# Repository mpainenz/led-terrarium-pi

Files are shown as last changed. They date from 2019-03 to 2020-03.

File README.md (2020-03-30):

<div class="main-content">
  <h2 id="how-to-build-your-own-raspberry-pi-powered-terrarium">Build your own Raspberry Pi powered Terrarium</h2>
  <p>Use a Raspberry Pi to control LED lighting for a terrarium. 
    Download the code I've shared on <a href="https://github.com/mpainenz/led-terrarium-pi">my Github page</a>, and build your own!
  </p>
  <ul>  
    <li>Changes colour throughout the sunrise, day, sunset, and night</li>  
    <li>Uses your geographical location to calculate the actual sunrise and sunset times to use</li>
  </ul>

  <h2 id="you-will-need">You will need...</h2>
  <ul>
    <li>A Raspberry Pi (any version will do)</li>
    <li>A Terrarium</li>
    <li>A White LED Light strip (to provide light to the plants)</li>
    <li>An RGB LED Light strip (to provide color effects)</li>
    <li>A 12v DC Power Supply</li>   
    <li>A 12v to 5v UBEC (Powers your Pi from the same 12v supply as the LED strips)</li>
    <li>A soldering iron and solder</li>
    <li>4 x MOSFET Transistors (Used in the lighting circuits)</li>
    <li>4 x Resistors (Also used in the lighting circuits)</li>
    <li>Various lengths of electrical wire</li>
  </ul>

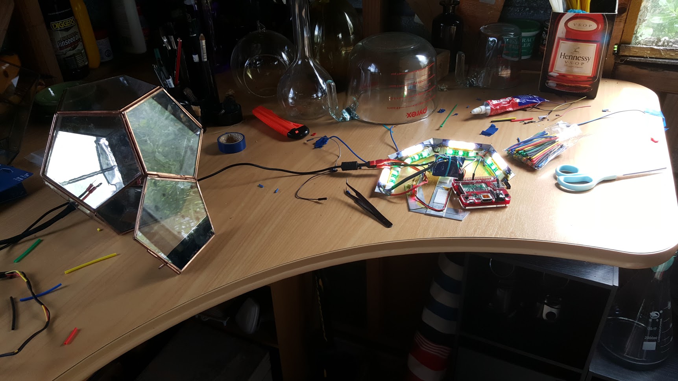
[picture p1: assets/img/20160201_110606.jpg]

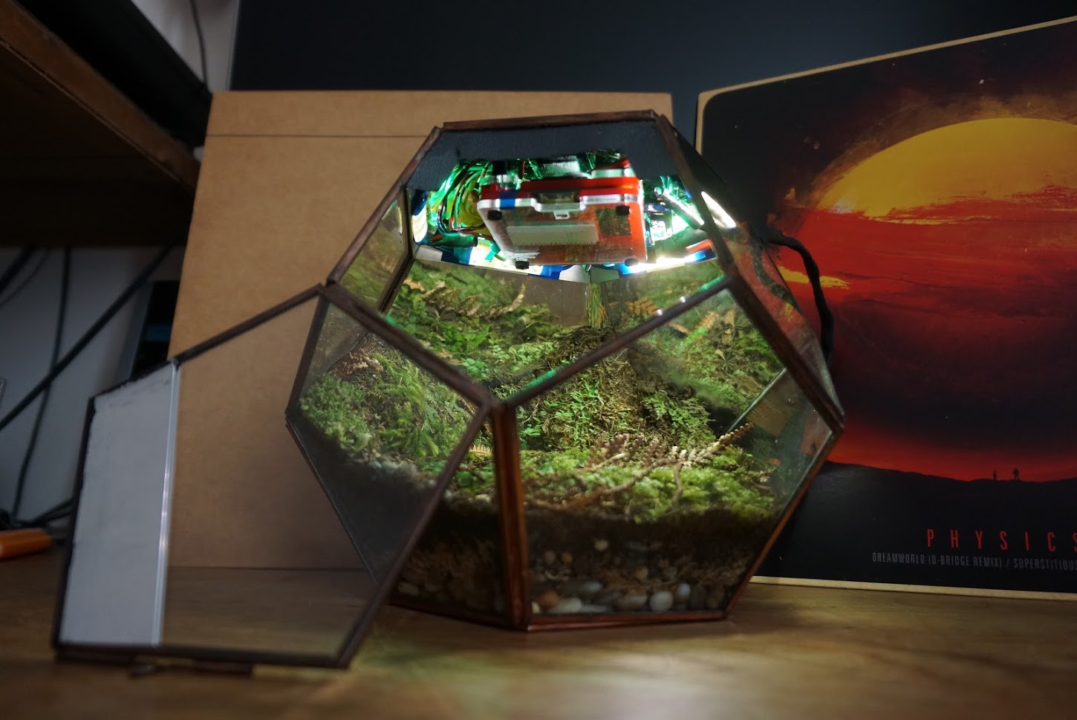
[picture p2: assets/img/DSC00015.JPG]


<h2 id="lets-get-started">Lets get started</h2>

<p>It might seem complicated, but it's pretty straight forward once we break it down into parts. Keep scrolling and we can go through each step. If you get stuck, feel free to send me an email. Perhaps I could make one for you?</p>
  
<p>Keep scrolling for more...</p>

</div>

<div class="main-content">

<h2 id="led-terrarium-pi">Powering the lights</h2>
<p>How can a Raspberry Pi control LED lighting?</p>

<p>All Raspberry Pi's come with a series of GPIO pins which you can control.</p>



<p>GPIO pins either accept an input voltage which can be read, or can be setup to output a voltage signal. In this case, we want to power our LED lights, so we want to output a signal. In our software, we tell the Raspberry Pi that we want to use three pins to control the RGB light strip (one for each colour), and one pin to control the White LED strip.</p>

<p>Sounds simple right? Unfortunately there are two problems...</p>

<ul>
  <li>The LED strips require 12 volts, but the GPIO pins only output 3.3 volts. </li>
  <li>The output voltage on the GPIO pins can either be 3.3v or 0v. There's no in-between. For an RGB light strip to show a full range of colours, or a white strip to be at varying brightnesses, we need the values in between the min and max voltage</li>
</ul>

<p>Fortunately, we have solutions to both of these issues. </p>

<h2 id="led-terrarium-pi">MOSFET</h2>

<p>Instead of using the Raspberry Pi GPIO pins to power the LED strips (which wouldn't work because the output voltage is too low at 3.3v when we need 12v), we will instead power the LED strips off a 12v power supply, and introduce a MOSFET into that circuit.</p>
  
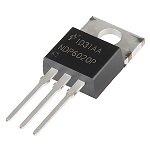
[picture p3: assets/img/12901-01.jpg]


<p>Think of the MOSFET here as a type of switch. The MOSFET has two circuits running through it. When current passes through one of those circuits, it opens the other circuit. </p>

<p align="center">
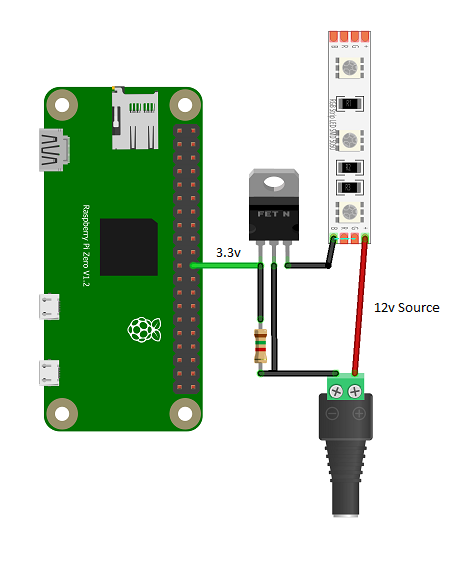
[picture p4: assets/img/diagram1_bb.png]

</p>

<p>We connect our Raspberry Pi and our LED light strip to our MOSFET. I've shown one MOSFET here, but we would need to add one per colour on the RGB strip, and another one for our White LED strip. Each of these are controlled separately to achieve a full colour spectrum.</p>

<p align="center">
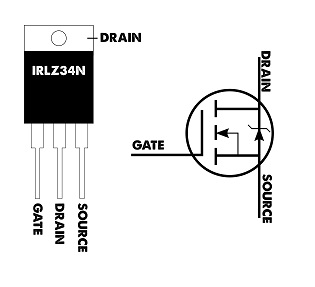
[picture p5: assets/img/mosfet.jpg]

</p>
  
<p>A MOSFET has three pins. From left to right, Gate, Drain, Source.</p>
<ul>
  <li>The Gate pin is what is connected to the Raspberry Pi, and is used to open the Source/Drain circuit. You might notice that we need to also connect the Gate pin to negative with a resistor. When voltage is applied to the Gate pin, it charges up like a capacitor, so it must also be attached to negative with a resistor. If you skip that step, the gate will remain open when voltage is not being applied. The resistor allows the Gate to discharge.</li>
  
  <li>The Source and Drain pins are attached to the LED circuit. Unless voltage is being applied to the Gate, this circuit remains closed.</li>
</ul>

<p>The part I have used here (Part Number IRLZ34N) is a perfect fit for a 12v LED light circuit. It is rated to work with the Raspberry Pi's 3.3v output and the 12v light circuit. There are two types of MOSFETS, and they are wired differently. This is an N-type MOSFET.</p>

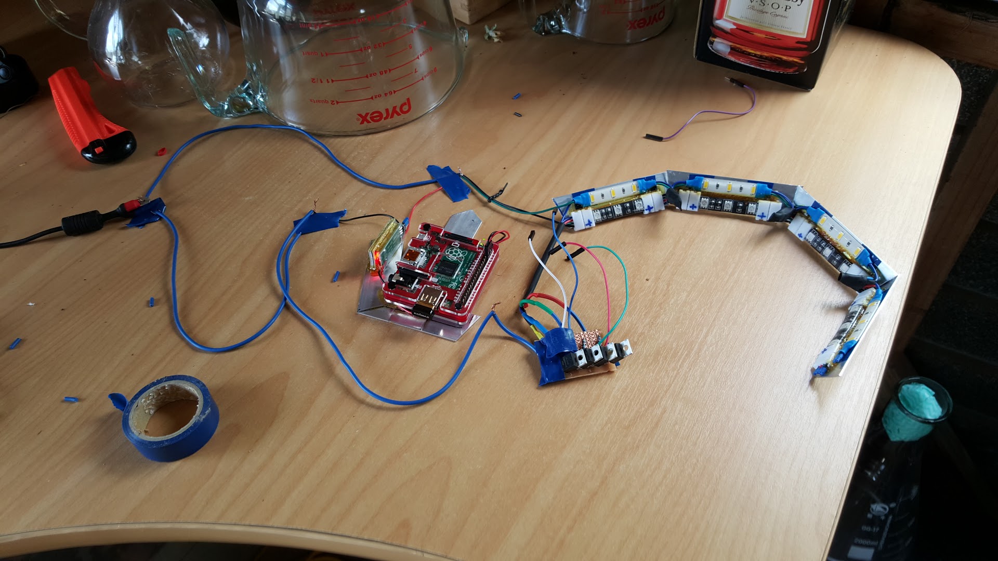
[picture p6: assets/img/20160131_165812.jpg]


<p>It can be helpful to use a little PCB board to attach the MOSFETs to. The image above was my first attempt. I ended up redoing this part, and not using a PCB. Instead I just used solder, wire, and heat shrink to save a little space.</p>

<p>You might notice that in the picture above, I'm also using the 12v power source to power the Raspberry Pi. The Raspberry Pi can accept 5v power into the GPIO interface. How do we step down from 12v to 5v? We can use a 12v to 5v UBEC. This accepts a 12v source, and outputs a 5v current. This step is optional, you could just use a normal 5v power supply, but I wanted to only have one cable going into the terrarium</p>

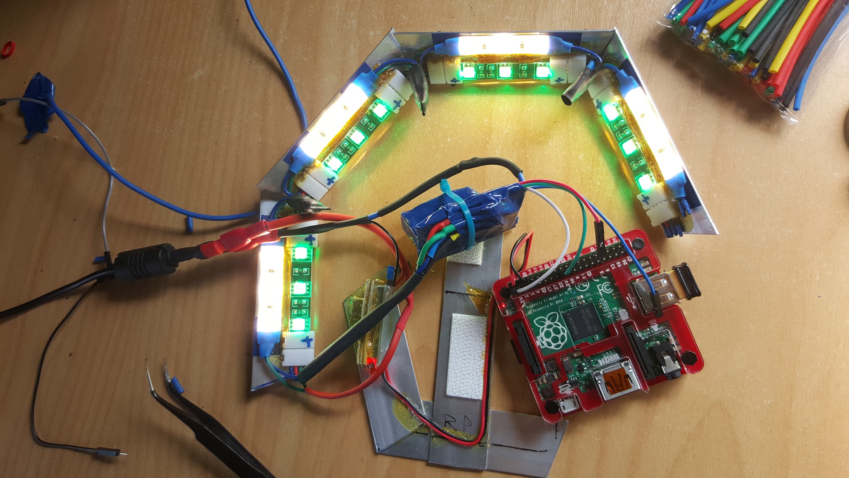
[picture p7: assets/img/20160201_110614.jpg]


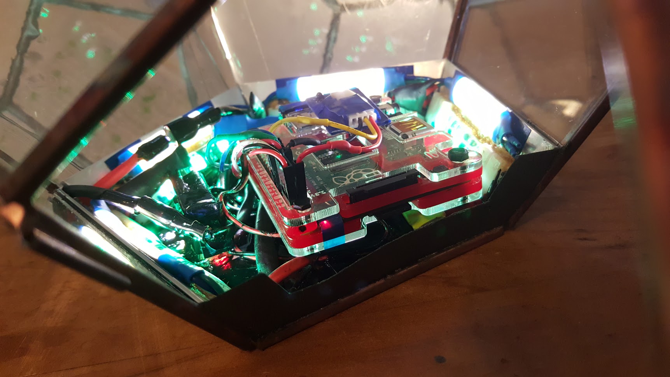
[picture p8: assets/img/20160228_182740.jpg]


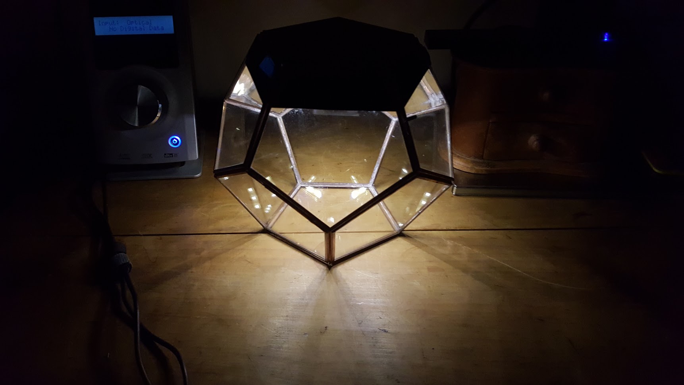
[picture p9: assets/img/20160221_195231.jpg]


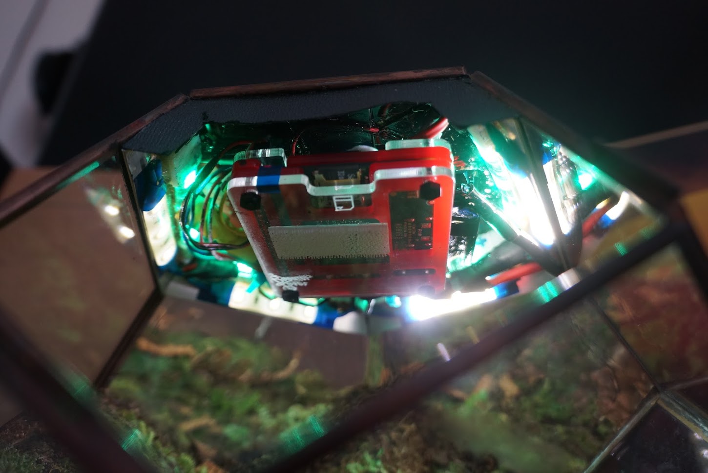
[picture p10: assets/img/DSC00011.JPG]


</div>

<div class="main-content">

<h2 id="led-terrarium-pi">Controlling the lights</h2>

<p>I mentioned earlier that there is another issue here. Our LED strips are analogue. They accept any current between 0v and 12v. For the RGB light strip, to generate a wide selection of colours, that means we want to use all sorts of voltages.</p>

<p>When the Raspberry Pi is instructed to send an output voltage to our MOSFET, it can only send either 0v or 3.3v. There is no in-between. If we could half the voltage and send 1.65v to the gate of the mosfet, we would expect around 6v of current on the light circuit.</p>

<p>So what can we do?</p>

<h2 id="led-terrarium-pi">Pulse Width Modulation</h2>

<p>Feel free to skip this section if you want, I've handled this in the code so you don't really need to understand this part. But if you are interested, what we can do is quickly alternate the output 3.3v signal on and off many times a second. We can then have the software turn that signal on for longer, or off for longer, depending on what voltage we want to try and emulate.</p>

<p align="center">
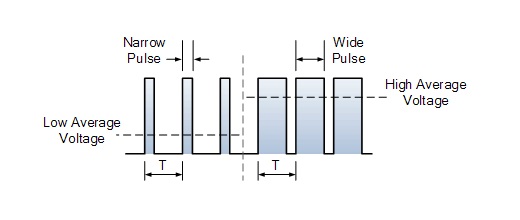
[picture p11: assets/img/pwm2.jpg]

</p>
  
</div>

<div class="main-content">

<h2 id="led-terrarium-pi">The fun part</h2>

<p>Now that the hard part is done, putting the terrarium together can start. For mine, I chose to try and build a closed terrarium and grow mosses, lichens, and other moisture loving plants.</p>

<p>To create a healthy enviroment for the plants, it's useful to create an area in the bottom of the container which contains either spagnum moss, or charcoal. My understanding is that this can help to prevent toxic compounds from lingering in the bottom where the water drains. It will help to prevent the envirment in the soil turning anaerobic, and will be more beneficial to the health of the overall system</p>

<p>For my terrarium, I used...</p>
  
  <ul>
    <li>Wild plants and mosses collected from nature</li>
    <li>Small rocks</li>
    <li>Medium sized rocks</li>
    <li>Cacti and Succulent Potting Mix (Formulated to drain very well)</li>
    <li>Spagnum Moss</li>
    <li>Charcoal</li>
    <li>A Coffee Filter</li>
  </ul>
  
<p align="center">
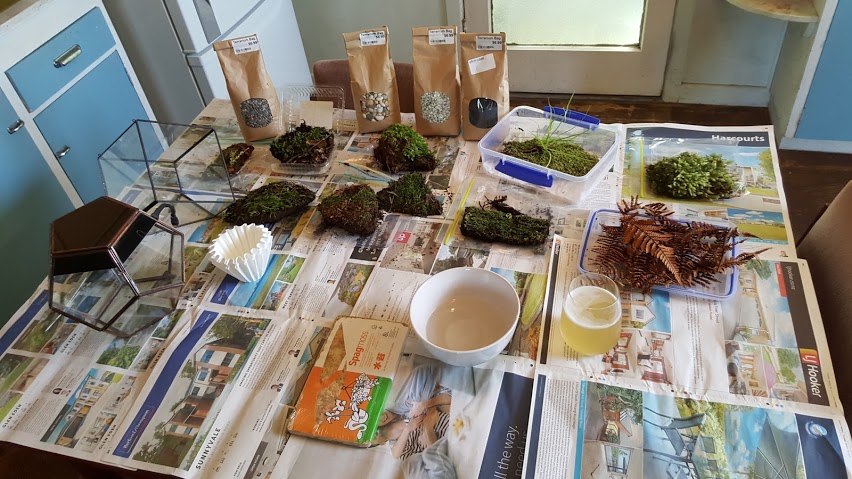
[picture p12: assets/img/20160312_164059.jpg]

</p>

<p>First I started with large rocks at the bottom</p>

<p align="center">
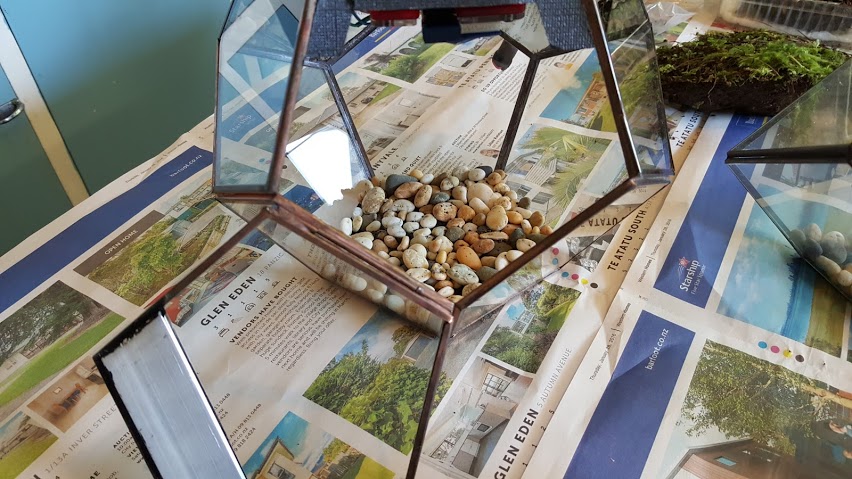
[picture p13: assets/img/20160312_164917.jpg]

</p>

<p>Next I placed a piece of Coffee filter paper on top </p>

<p align="center">
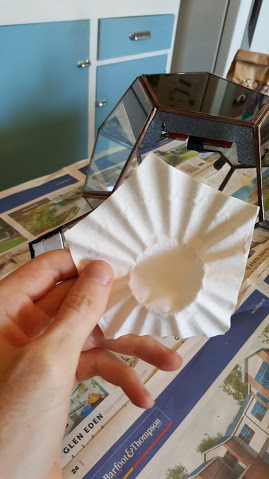
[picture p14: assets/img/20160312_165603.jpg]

</p>

<p>And on top of that, a combination of Spagnum Moss and crushed Charcoal (be sure not to use any charcoal that might have a chemical accelerant added to it to help it burn faster)</p>

<p align="center">
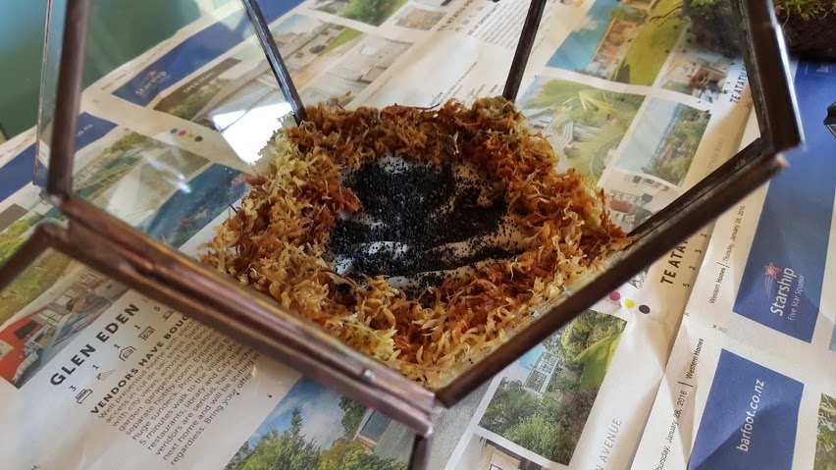
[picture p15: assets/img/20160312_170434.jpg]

</p>

<p>On top of that some small rocks</p>

<p align="center">
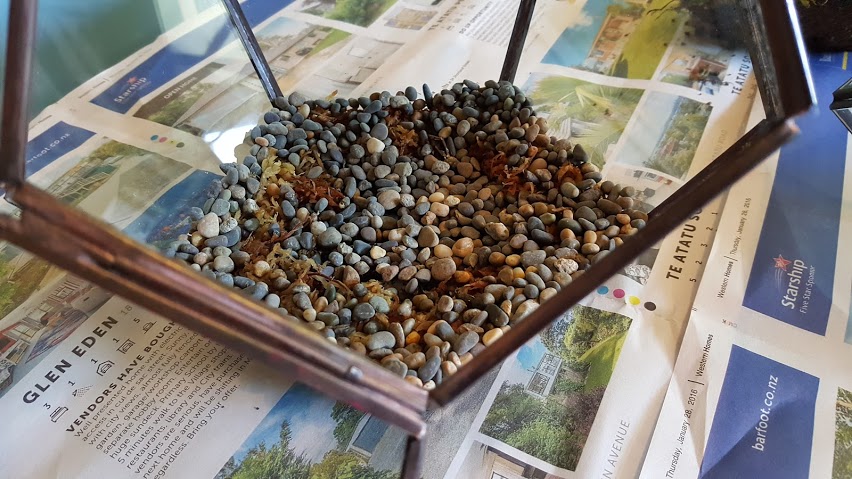
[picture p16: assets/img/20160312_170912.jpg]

</p>

<p>And on top of that some potting mix</p>

<p align="center">
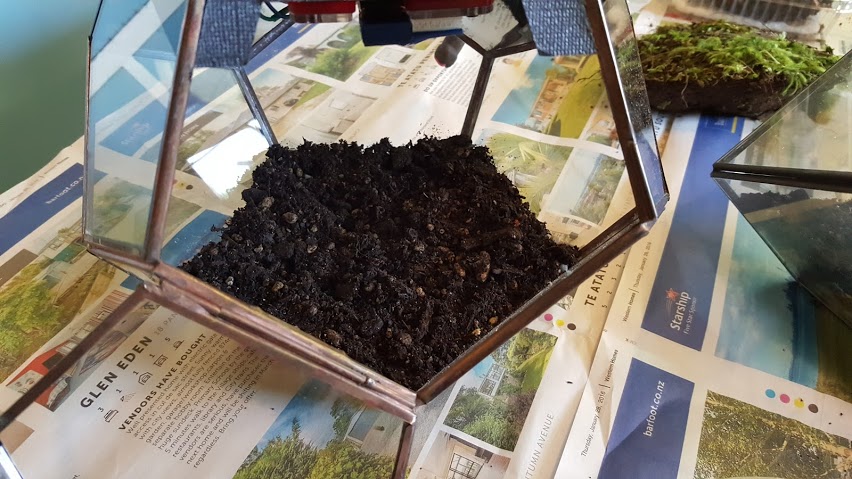
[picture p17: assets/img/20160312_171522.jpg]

</p>

<p>Now that we have a functional drainage and bedding layer, the plants can be added. This part was difficult to photograph, but essentially it's a bit of a jigsaw puzzle, and is really an art form in itself. </p>

<p align="center">
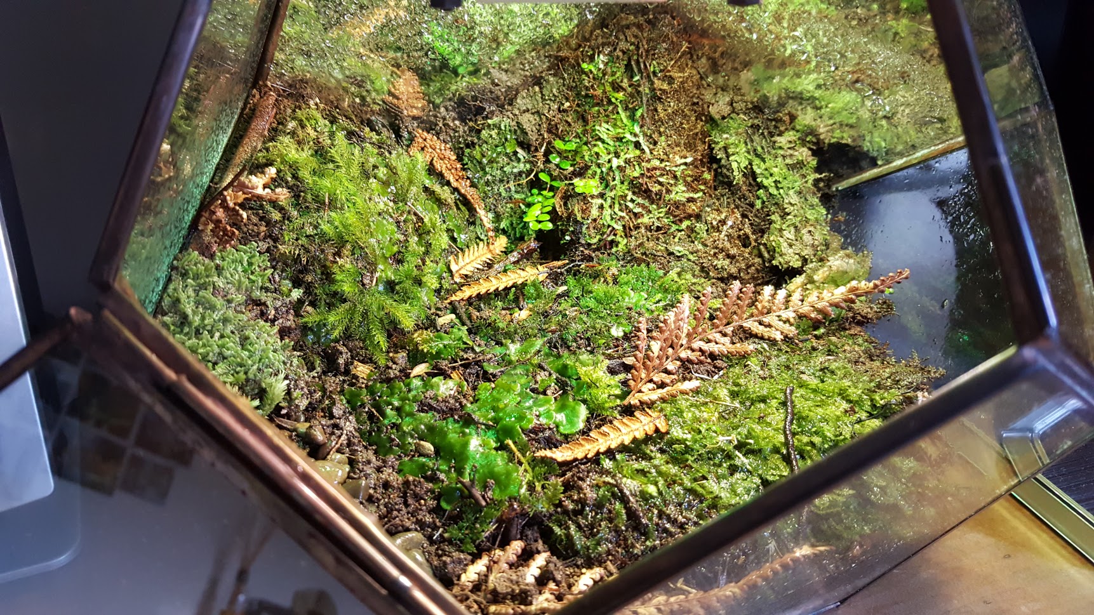
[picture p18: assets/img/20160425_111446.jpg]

</p>

</div>

<div class="main-content">

<h2 id="led-terrarium-pi">Installing the software</h2>

<p>Firstly prepare a Rasperry Pi by installing Raspian OS, and set the Timezone on your Raspberry Pi with ‘sudo raspi-config’ command. (Defaults to UTC)</p>

<p>Requirements:</p>
<ul>
  <li>Python 2.7 (comes by default)</li>
  <li>pigpio (comes by default)</li>
</ul>

<p>Python Libraries</p>
<ul>
  <li>ephem (Astronomical library to work out Sunrise/Sunset) - <code class="highlighter-rouge">sudo pip install ephem</code></li>
</ul>

<p>To install my light controller script, simply copy the main.py, terrarium_lights.py, and config.py files to a directory of the Raspberry Pi, and type the following commands</p>

<code class="highlighter-rouge">pigpiod</code>

<code class="highlighter-rouge">sudo python main.py</code>

<p>The first command starts the GPIO daemon, and the second command runs my script. The GPIO daemon is the software the Raspberry Pi uses to send and receieve signals over the GPIO interface</p>

<h2 id="led-terrarium-pi">Changing your settings</h2>

<p>Modify the config.py file and provide your latitude & longitude to allow the script to give you the correct day/night cycle for your location.</p>

<p>Optionally you can also specify which GPIO pins to use. The default is as follows:</p>
<ul>
  <li>Red: 25</li>
  <li>Green: 27</li>
  <li>Blue: 22</li>
  <li>White: 18</li>  
</ul>

<h2 id="about-me">About me</h2>
<p>Hi, My name is Mark Paine, I'm a software developer based in New Zealand. I love nature, electronics, and programming. It was great to combine it all together and produce this guide. I hope you enjoyed reading it.</p>

<p>If you have any questions or comments, feel free to get in touch either here in the 'issues' section of the GitHub page, or via email on <a href = "mailto: mpainenz@gmail.com">mpainenz@gmail.com</a></p>

<p>If you create your own terrarium using this guide, send me a photo.</p>

<p>Do you love this Terrarium, but can't build your own? Perhaps I can build you one? Get in touch. :)</p>

</div>

<div class="main-content">

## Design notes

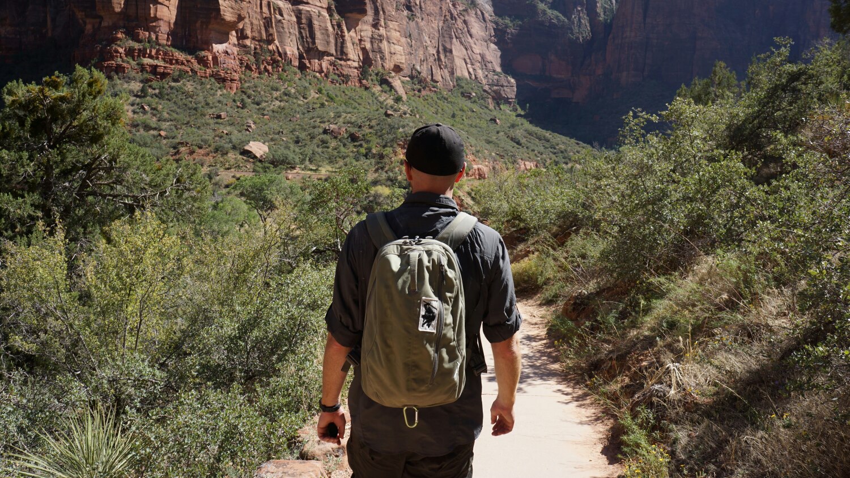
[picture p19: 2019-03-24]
assets/img/51833_10151268154790850_972230833_o.jpg

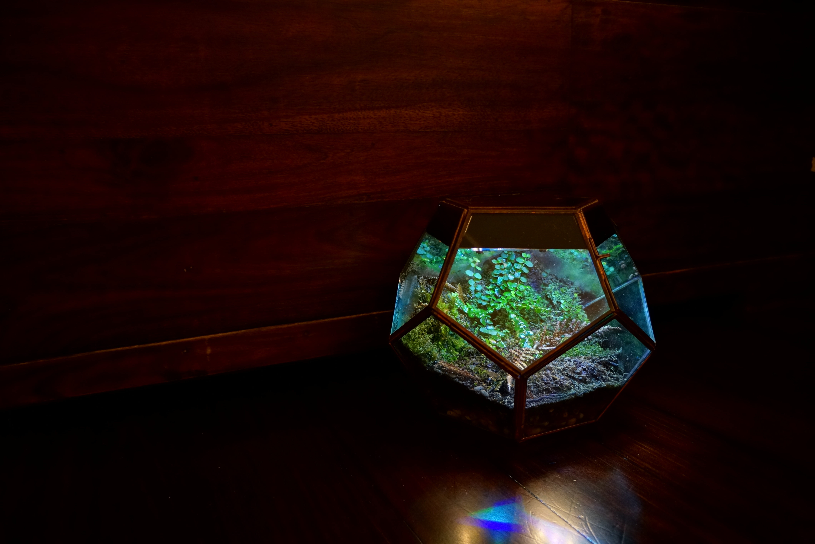
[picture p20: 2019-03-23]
assets/_source/Header_Original.JPG

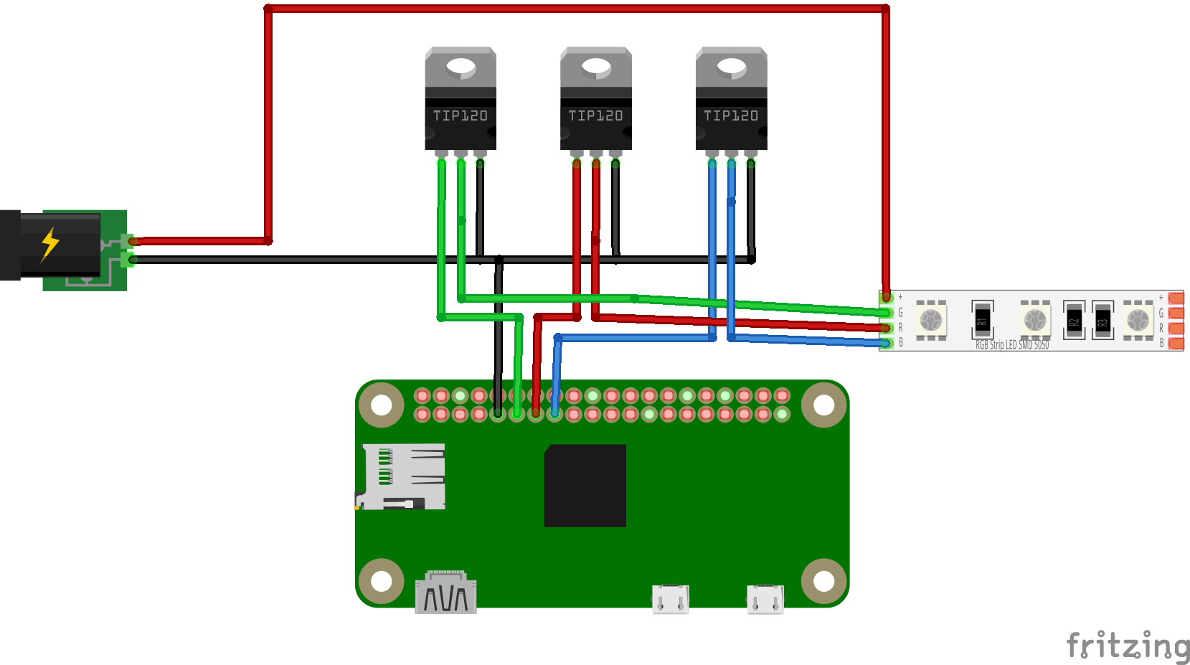
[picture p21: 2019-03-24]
assets/img/1_r30X-Br2KrpMM11rT-B4mQ.png

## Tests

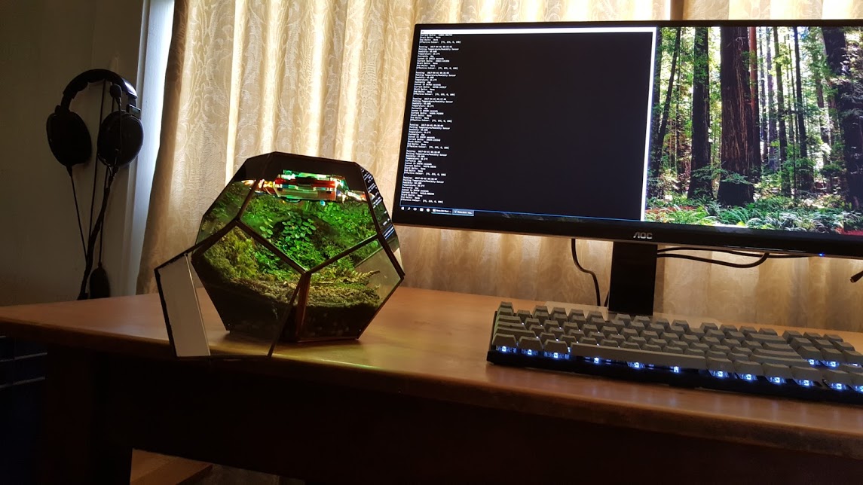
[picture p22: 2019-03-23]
assets/img/test2.jpg

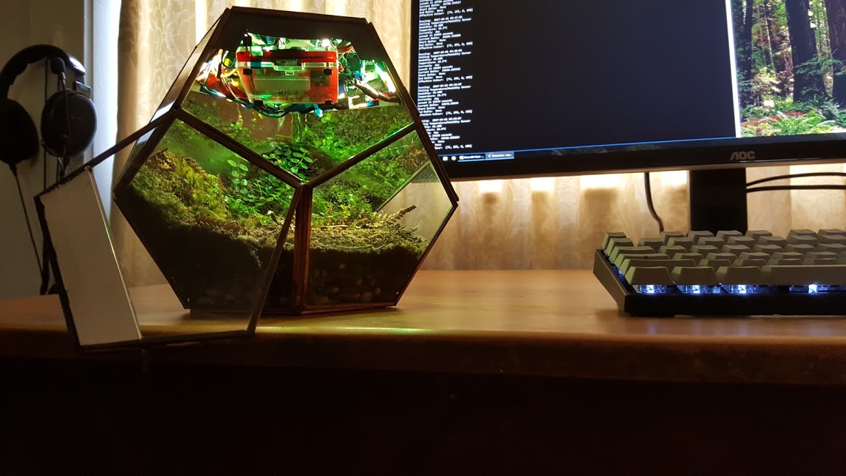
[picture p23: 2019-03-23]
assets/img/test.jpg

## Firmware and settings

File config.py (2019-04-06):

#import Adafruit_DHT

# GPIO Channel for RGB LED Strip
r_channel = 25
g_channel = 27
b_channel = 22

# GPIO Channel for white LED Strip
w_channel = 18

# Location Latitude and Longitude (Auckland, New Zealand)
latitude = "-36.84"
longitude = "174.74"


# RGBW Value to use during Day
day_colour = [75, 255, 0, 100]

# RGBW Value to use during Night
#night_colour = [0, 200, 200, 0]
night_colour = [0, 100, 100, 0]


# Sunset/Sunrise RGB & White LED Colour values over time
#             Time (Seconds)    R,  G,  B,  W

# 60 = 1 Minute
# 3600 = 1 hour
sunrise_colour_map = {  3600: night_colour,
                        3000: [  0,  50, 100,  15],  #Dim Blue
                        2400: [100,  30,  30,  30],  #Neutral
                        1800: [255,   0,   0, 60],  #Very Red
                        1500: [255, 100,   0, 80],  #Sepia dimmer
                        1200: [255, 200,   0, 100],  #Sepia Light
                         900: [ 75, 255,   0, 100],  #Warmer Daylight
                           0: day_colour }     # Bright white


sunset_colour_map = {   3600: day_colour,
                        3000: [ 75, 255,   0, 100],  #Warmer Daylight
                        2400: [255, 200,   0, 100],  #Sepia Light
                        1800: [255, 100,   0,  80],  #Sepia dimmer
                        1500: [255,   0,   0,  60],  #Very Red
                        1200: [100,  30,  30,  30],  #Neutral
                         900: [  0,  50, 100,  15],  #Dim Blue
                           0: night_colour }




# Set to true to run through Sunrise colours in Demo mode
DEMO_MODE = False # Fast forward mode
DEMO_SPEED = 10 #1 sec = x sec

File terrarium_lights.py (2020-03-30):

import collections
import sys
import config
import time, datetime, pigpio
from datetime import timedelta
import argparse
import ephem


# Debug statements to help diagnose issues when Python wont run this script
# print(sys.executable)
# import os
# print(os.getcwd())
# print(sys.path)
# import platform
# print(platform.python_version())


class TerrariumLights:
    demo_time = None  # Used instead of current time when in Demo mode

    LOG_TIME_FORMAT = '%Y-%m-%d %H:%M:%S'

    # Temp and Humidity
    temperature = None
    humidity = None

    # Date/Time of Sunrise/Sunset
    previous_sunrise = None
    sunrise = None
    sunset = None

    def __init__(self, test_mode=False):

        self.test_mode = test_mode

        # Parse Aruments
        parser = argparse.ArgumentParser(description='Service to control LED Lighting in a Terrarium')
        parser.add_argument("r", nargs='?', default=0)
        parser.add_argument("g", nargs='?', default=0)
        parser.add_argument("b", nargs='?', default=0)
        parser.add_argument("w", nargs='?', default=0)
        args = parser.parse_args()

        print "Starting Auto LED Controller"
        self.start_time = time.time()

        print "Initializing connection to pigpio daemon"
        # pigpio daemon is required for accurate PWM timing
        if not self.test_mode:
            self.pi = pigpio.pi()

        if any(x > 0 for x in (args.r, args.g, args.b, args.w)):
            self._set_rgb_led(r=args.r, g=args.g, b=args.b)
            self._set_white_led(w=args.w)
            time.sleep(0.5)
            self.pi.stop()
            # time.sleep(3)
            sys.exit(0)

        print "Initializing Temp/Humidity sensor"
        # Sensor should be set to Adafruit_DHT.DHT11,
        # Adafruit_DHT.DHT22, or Adafruit_DHT.AM2302.

        # self.s = config.sensor

        if config.DEMO_MODE:
            print "Running in Demo Mode"
            self.demo_time = datetime.datetime.now()
            self._get_sunrise_sunset(self.demo_time)
            # Go to the start of Sunset
            self.demo_time = self.sunrise - datetime.timedelta(0, config.sunrise_colour_map.keys()[0])

        # try:
        while True and not self.test_mode:
            if config.DEMO_MODE:
                self._run(self.demo_time)
                self.demo_time = self.demo_time + datetime.timedelta(0, config.DEMO_SPEED)
                time.sleep(1)
            else:
                self._run(datetime.datetime.now())
                time.sleep(60)
        # except Exception as e:
        #     self.pi.stop()
        #     print 'Error: ', e.message

    def _run(self, now):
        print 'Running: ', self._timestamp(now)
        self._get_sunrise_sunset(now)
        # if not config.DEMO_MODE:
        # if self._get_temp_and_humidity():
        #    if config.ENABLE_DB:
        #        self._save_to_db(self.temperature, self.humidity)
        #    #self._update_graphs()
        self._update_lighting(now)
        print ''
        sys.stdout.flush()

    def _get_sunrise_sunset(self, now):

        if None in (self.sunrise, self.sunset) \
                or now > self.sunrise \
                or now > self.sunset:

            print "Calculating sunrise and sunset times"
            o = ephem.Observer()
            # o.horizon = -6 #http://rhodesmill.org/pyephem/rise-set.html#naval-observatory-risings-and-settings
            if config.DEMO_MODE:
                o.date = now - (datetime.datetime.now() - datetime.datetime.utcnow())  # ephem uses UTC Time
            o.lat = config.latitude
            o.long = config.longitude
            s = ephem.Sun()
            s.compute()

            try:
                self.last_sunrise = ephem.localtime(o.previous_rising(s))
            except (ephem.AlwaysUpError, ephem.NeverUpError):
                print 'got that damn error'
                pass

            self.sunrise = ephem.localtime(o.next_rising(s))

            self.sunrise += timedelta(
                hours=1)  # Terrarium was bright too early. Sunrise calculation may be slightly out, potentially an issue with how Sunrise is calculated versus what a person on the ground sees. IE Actual Astronomical Sunrise may be calculated from the moment the sun is in position, rather than when the sunrise looks to be happening.

            self.sunset = ephem.localtime(o.next_setting(s))

            print "Date: ", ephem.localtime(o.date)

            print "Latitude: %s" % o.lat
            print "Longitude: %s" % o.long
            print "Previous Sunrise: %s" % self._timestamp(self.previous_sunrise)
            print "Next Sunrise: %s" % self._timestamp(self.sunrise)
            print "Next Sunset: %s" % self._timestamp(self.sunset)

    def _update_lighting(self, effective_time):
        is_light = self.sunrise > self.sunset
        if is_light:
            effective_colour = config.day_colour
            current_phase, next_phase = 'day', 'sunset'
            delta = (self.sunset - effective_time).total_seconds()
            colour_map = config.sunset_colour_map
        else:
            effective_colour = config.night_colour
            current_phase, next_phase = 'night', 'sunrise'
            delta = (self.sunrise - effective_time).total_seconds()
            colour_map = config.sunrise_colour_map

        print "Currently ", current_phase

        start_delta, start_colour = self.get_start_colour_from_map(delta, colour_map)
        if start_delta is not None:
            blending_required = True
            effective_colour = start_colour
            end_delta, end_colour = self.get_end_colour_from_map(delta, colour_map)
        else:
            blending_required = False
            end_delta = None
            end_colour = None
            print "%s in %d seconds" % (next_phase, delta)

        if blending_required:
            blend_percentage = self.get_blend_percentage(delta, start_delta, end_delta)
            effective_colour = self.blend_colours(start_colour, end_colour, blend_percentage)
            print "Blend Percentage: ", blend_percentage
            print "Start Colour: ", start_colour
            print "End Colour: ", end_colour

        print "Current Delta: ", delta
        print "Start Delta: ", start_delta
        print "End Delta: ", end_delta
        print "Effective Colour: ", effective_colour

        # Update LEDs
        if (effective_colour[0] >= 0) and (effective_colour[1] >= 0) and (effective_colour[2] >= 0) and (
                effective_colour[3] >= 0):
            self._set_rgb_led(r=effective_colour[0], g=effective_colour[1], b=effective_colour[2])
            self._set_white_led(w=effective_colour[3])

    def get_start_colour_from_map(self, delta, colour_map):
        delta_result, colour_result = None, None

        sorted_colour_map = collections.OrderedDict(sorted(colour_map.items()))
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

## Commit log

2016-08-25 Updated DB Config to allow no DB correctly
    [config.py]
2020-03-30 Fix to issue with wrong colour being selected
    [terrarium_lights.py]
